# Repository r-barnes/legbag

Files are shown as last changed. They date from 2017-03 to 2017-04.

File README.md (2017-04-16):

The TOMBerkeley Leg Bag
=======================

This is a smartphone-controlled (via Bluetooth) device for emptying a leg bag
and monitoring how full said leg bag is.

Files
=====

 * `arduino`:                Contains the Arduino code for the project
 * `com.tomberkeley.legbag`: Contains a Cordova project

Diagrams
========

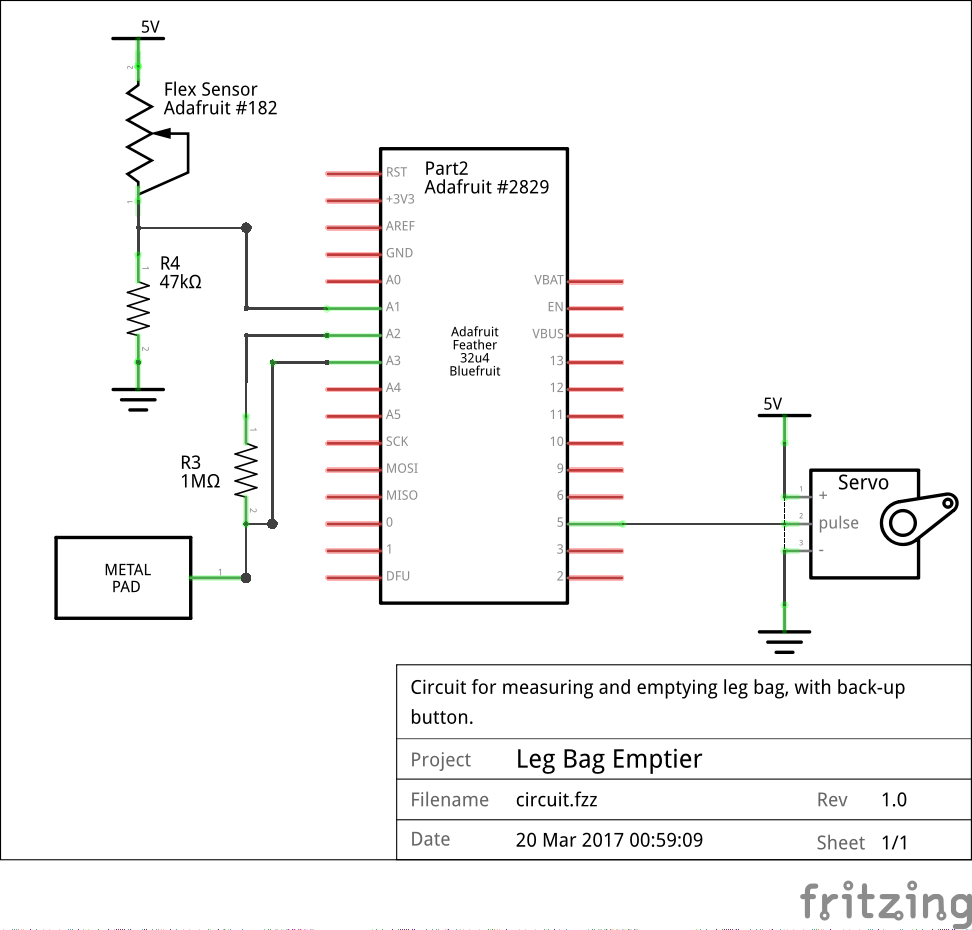
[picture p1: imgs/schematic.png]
Leg Bag Emptier circuit diagram


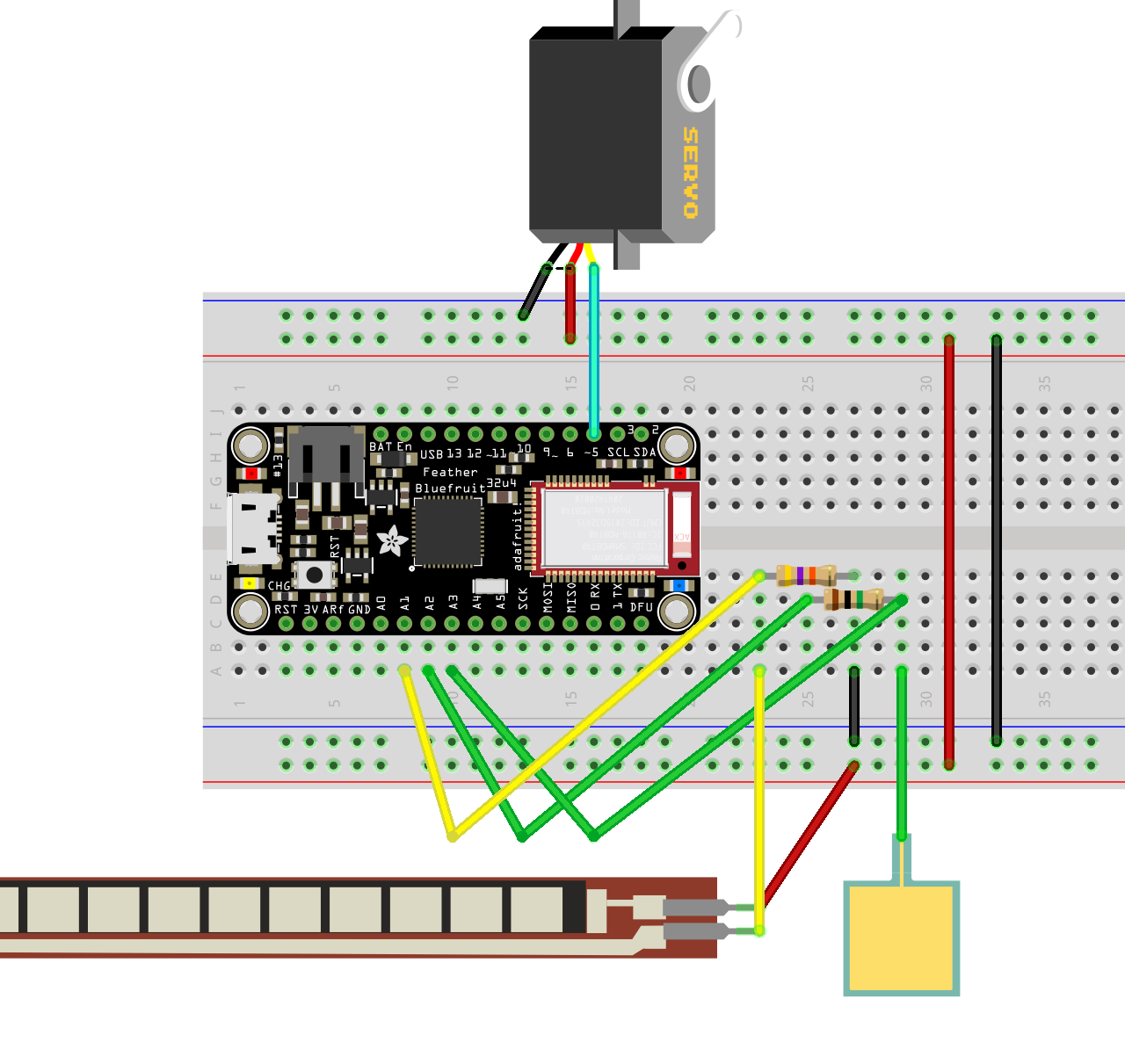
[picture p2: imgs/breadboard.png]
Leg Bag Emptier breadboard diagram


Debugging
============

On Android with Google Chrome you can debug the app by enabling **Developer
Mode** on the phone and then enabling **USB Debugging**. You can then go to
[chrome://inspect](chrome://inspect) to see what's happening on the app.

Contributors
============
 * Ali Nazari
 * Richard Barnes (rijard.barnes@gmail.com, http://rbarnes.org, Github: r-barnes)
 * Jorge Ruiz
 * Katherine Lau
 * Nupur Kaku
 * Rafe Biggs
 * Viola Quach

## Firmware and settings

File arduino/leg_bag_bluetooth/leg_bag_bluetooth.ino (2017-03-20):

//Leg Bag Control Program
//By: Richard Barnes (richard.barnes@berkeley.edu, http://rbarnes.org)
//Use with: Adafruit Feather 32u4 Bluefruit LE

/*
This program sets up the Feather's Bluetooth with a custom channel name. Once
connected, it accepts UART serial input via Bluetooth. The program accepts the
following commands:

    Command | Action
    ----------------------------------------------------------------------------
    O       | Opens the bag by turning the servo to its 0 degree position
    C       | Closes the bag by turning the servo to its 90 degree position

The program assumes the existence of several external devices:

    Sensor  | Description
    ----------------------------------------------------------------------------
    Servo   | Opens and closes the bag by toggling between two positions.
            |
    Flex    | A strip whose resistence increases when it is bent. Sampled by
            | connecting it as part of a voltage divider.
            |
    Touch   | A metal plate serving as a capacitor in an RC circuit. The charge
              time of the circuit is used to determine if the plate has been
              touched.

*/

#include <Arduino.h>
#include <SPI.h>
#include <Servo.h>

#include "Adafruit_BLE.h"
#include "Adafruit_BluefruitLE_SPI.h"
#include "Adafruit_BluefruitLE_UART.h"
#include "BluefruitConfig.h"

#include "CapacitiveSensor.h"

typedef unsigned long time_t;

//PINS
#define SERVO_CONTROL_PIN                 5  //Pin servo will be controlled by
#define FLEX_SENSOR_PIN                  A1  //Reads flex sensor
#define TOUCH_EMITTER_PIN                A2  //Sends signal to touch sensor
#define TOUCH_SENSOR_PIN                 A3  //Reads signal from touch sensor

//Debugging control
//ENSURE BOTH OF THESE ARE SET TO 0 (ZERO) FOR PRODUCTION
#define DEBUG_MODE                        0  //Show debugging info in Serial
#define FACTORYRESET_BLE                  1  //R

#define MINIMUM_FIRMWARE_VERSION    "0.6.6"  //Used only to determine what BLE LED can do.
#define MODE_LED_BEHAVIOUR            "SPI"  //BLE LED behavior. Values: DISABLE, MODE, BLEUART, HWUART, SPI, MANUAL

#define BLE_DEVICE_NAME  "LegBagController"  //Name other Bluetooth devices see when scanning

#define SERVO_MIN_POS_PW                700  //Pulse width corresponding to minimum position of servo
#define SERVO_MAX_POS_PW               2300  //Pulse width corresponding to maximum position of servo
#define SERVO_OPEN_BAG_DEGREES            5  //Position in degrees at which servo has opened bag
#define SERVO_CLOSE_BAG_DEGREES          57  //Position in degrees at which servo has closed bag

//Backup touch sensor to open bag
#define SECS_TO_OPEN_BAG_ON_TOUCH         5  //How many seconds the bag should be opened for when the touch sensor is activated

//Measure the voltage at 5V and the actual resistance of your
#define SECS_BETWEEN_FLEX_SAMPLES         1  //Seconds each sample-and-send of the flex sensor
const float FLEX_VCC = 4.98;    //Measured voltage of Arduino 5V line
const float FLEX_R   = 47500.0; //Measured resistance of voltage divider's second resistor
time_t next_flex_sample_ms = 0;

//We'll connect to the servo only when we're using it in order to reduce wear
//and save energy. The servo's neutral position (90 degrees) is closed for the
//tube.
Servo myservo;

//For touch button
CapacitiveSensor touch_sensor = CapacitiveSensor(TOUCH_EMITTER_PIN,TOUCH_SENSOR_PIN);

//Bluetooth device
Adafruit_BluefruitLE_SPI ble(BLUEFRUIT_SPI_CS, BLUEFRUIT_SPI_IRQ, BLUEFRUIT_SPI_RST);

//Time to close the bag again. This is set to a non-zero value if the touch
//sensor is activated and indicates the time, in milliseconds, when the bag
//should next be closed.
time_t close_bag_time_ms = 0;


//Function for handling errors
void error(const __FlashStringHelper*err) {
  if(DEBUG_MODE){ //TODO: What to do if there's an error when not in debug mode?
    Serial.println(err);
    while (1);
  }
}



//Performs whatever actions are necessary to open the bag
void OpenBag(){
  //Connect to the servo and move it to the open position
  myservo.attach(SERVO_CONTROL_PIN,SERVO_MIN_POS_PW,SERVO_MAX_POS_PW); 
  myservo.write(SERVO_OPEN_BAG_DEGREES);
}



//Performs whatever actions are necessary to close the bag
void CloseBag(){
  myservo.write(SERVO_CLOSE_BAG_DEGREES);   //Move the servo to its closed position
  delay(2000);         //Give it 2 seconds to get there, so we don't stop in an intermediate position
  myservo.detach();    //Disconnect from the servo
}



//Reads from the backup touch sensor
inline void HandleTouchSensor(time_t now_ms){
  long touch_value = touch_sensor.capacitiveSensor(30);

  if(DEBUG_MODE){
    Serial.print("touch ");
    Serial.println(touch_value);
  }

  if(touch_value>400 && close_bag_time_ms==0){
    close_bag_time_ms = now_ms+SECS_TO_OPEN_BAG_ON_TOUCH*1000;
    OpenBag();
  }

  if(close_bag_time_ms>0 && now_ms>close_bag_time_ms){
    close_bag_time_ms = 0;
    CloseBag();
  }
}



//Reads the flex sensor and tries to send information about it over Bluetooth
inline void ReadAndSendFlex(time_t now_ms){
  if(now_ms<next_flex_sample_ms)
    return;

  next_flex_sample_ms = now_ms+SECS_BETWEEN_FLEX_SAMPLES*1000;

  auto  flexADC = analogRead(FLEX_SENSOR_PIN);       //Level units from ADC
  float flexV   = flexADC * FLEX_VCC / 1023.0;       //Measured voltage from voltage divider
  float flexR   = FLEX_R * (FLEX_VCC / flexV - 1.0); //The resistance of the flex sensor

  char output[BUFSIZE+1] = "HELLO\n\0";

  // Send input data to host via Bluefruit
  ble.print(flexR);

  if(DEBUG_MODE){
    Serial.println(output);
    Serial.println(flexR);
  }
}



//Used by the main loop to read Bluetooth
inline void HandleBluetoothInput(){
  while ( ble.available() ){
    int c = ble.read();

    if(c=='O')        //Open
      OpenBag();
    else if(c=='C')  //Close
      CloseBag();

    if(DEBUG_MODE)
      Serial.println((char)c);
  }
}



//This is run when the Arduino boots up after a power cycle
void setup(){
  if(DEBUG_MODE){
    while (!Serial);           //Required for Flora & Micro
    Serial.begin(115200);
  }

  delay(500);                  //Wait for the board to settle? TODO

  if(!ble.begin(VERBOSE_MODE)) //Initialize the BlueFruit
    error(F("Error initailizing Bluetooth!"));

  if (FACTORYRESET_BLE){       //Ensure everything is in a known state
    if(!ble.factoryReset())    
      error(F("Couldn't factory reset"));
  }

  //Set Bluefruit name, as seen by other Bluetooth devices
  ble.println("AT+GAPDEVNAME=" BLE_DEVICE_NAME);

  if (!ble.waitForOK())
    error(F("Failed to set Bluetooth name."));

  ble.echo(false);             //Disable command echo from Bluefruit
  if(DEBUG_MODE)
    ble.info();
  ble.verbose(false);          //Disable debug info from Bluefruit

  while(!ble.isConnected())    //Wait for a BLE connection
    delay(500);

  //LED Activity command is only supported from 0.6.6 onwards
  if ( ble.isVersionAtLeast(MINIMUM_FIRMWARE_VERSION) )
    ble.sendCommandCheckOK("AT+HWModeLED=" MODE_LED_BEHAVIOUR);

  //Set module to DATA mode
  ble.setMode(BLUEFRUIT_MODE_DATA);

  //Pin used for flex sensor
  pinMode(FLEX_SENSOR_PIN, INPUT);

  if(DEBUG_MODE)
    Serial.print("Setup finished!");
}



//Main loop: this runs continuously during program operation
void loop(){
  time_t now_ms = millis();

  HandleTouchSensor(now_ms);

  ReadAndSendFlex(now_ms);

  HandleBluetoothInput();
}

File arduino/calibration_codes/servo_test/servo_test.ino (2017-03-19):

/*
Servo Tester
By: Richard Barnes (richard.barnes@berkeley.edu, http://rbarnes.org)

A servo works by moving to a position determined by a signal of varying pulse
width. The width of the pulse determines which position the servo moves to.
Position is a linear function of the pulse width.

Therefore, with an unknown servo, our goal is to determine the pulse widths
corresponding to the servos minimum and maximum positions.

To do this, hook up the servo as follows:

  Power:  Connect the red wire from servo to +5V (USB or external power supply).

  Ground: Connect black/brown wire from servo to Gnd on Arduino. Ensure the 
          foregoing power supply shares this ground.

  Signal: Connect white/orange/yellow from servo to a PWM pin on Arduino.
          I like Pin 5.

Then load this onto your Arduino. You can then enter pulse widths into the
serial monitor and observe where the servo goes. Experimentally determine the
minimum and maximum positions by looking for the lowest value that brings the
servo to its maximum range and the highest value that brings it to its minimum
range. You may need to increase or decrease MIN_POS_PW and MAX_POS_PW to reach
the full range of the servo.

For instance, with the Standard HiTEC HS-311 servo I'm currently testing, I find
the following values:

    Pulse Width | Position    | Note
            600 | 0 degrees   | Minimum position
           2400 | 180 degrees | Maximum position

Note that the 1500 pulse width would correspond to 90 degrees: the middle of the
range.

Once I know these values, I can declare a Servo object as in the code here and
place it to an exact position using:

    myservo.write(<DEGREES>);

*/
 
#include <Servo.h>

#define MIN_POS_PW  600
#define MAX_POS_PW 2400

Servo myservo;

void setup() {
  //Attach to a PWM pin, in this case 5. Set minimum position to 600 and maximum
  //to 2400. The servo will start at 1500, which is the center position for most
  //servos.
  myservo.attach(5,MIN_POS_PW,MAX_POS_PW); 
}

void loop() {
  if ( Serial.available()) {
    long a = Serial.parseInt();
    if(a==0) return; //parseInt returns a belated 0. This is the easiest way to disregard that.
    myservo.writeMicroseconds(a);
  }
}

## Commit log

2017-03-19 Abstract the bag control pin
2017-03-19 Send appropriate signals to Arduino.
2017-03-19 Added stop button
2017-03-19 Added Stop Button and Progress bar.
2017-03-19 Add subscriptions: useful for fullness sensor
2017-03-19 Add description of sensors
2017-03-19 Abstract main loop sections. Clarify pins. Add touch sensor. Add flex sensor.
    [leg_bag_bluetooth.ino]
2017-03-20 Added circuitry images
2017-03-20 Updated image. Added circuit file.
    [circuit.fzz]
2017-04-16 Plugin to figure out what device we're on and Toast plugin to send little notices to the user
2017-04-16 Oops! I forgot to add the capacitive sensor files!
